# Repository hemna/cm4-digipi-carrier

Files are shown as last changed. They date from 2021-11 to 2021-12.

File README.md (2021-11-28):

# Raspberry Pi Compute Module 4 (CM4) Carrier Template

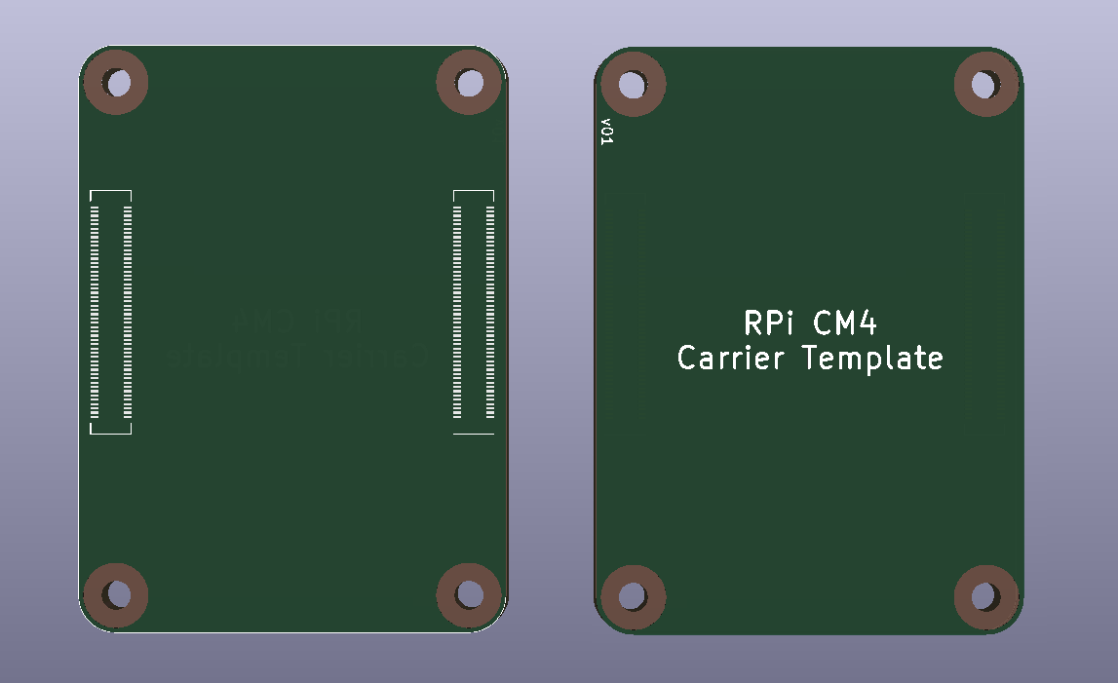
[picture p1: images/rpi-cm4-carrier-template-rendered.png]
Rendered example of RPi CM4 Carrier Template PCB


A template to help you design your own Raspbeery Pi Compute Module 4 carrier board (or daughterboard). The template comes with the CM4 KiCad library and gives an initial placement of Hirose connectors.

Note that a board outline has been added to be the exact size and shape of the CM4 board. This allows you to keep a neat stackup on your carrier board. However, feel free to mvoe/delete the board outline if you wish to make the carrier board extend beyond the edges of the CM4 (e.g. you wish to add a PCIe connector).

**IMPORTANT!** This project require KiCad 6. As KiCad 6 is not out yet, you will need to install a [nightly build of KiCad](https://kicad-downloads.s3.cern.ch/index.html?prefix=windows/nightly/). As a result, you may find bugs in the pre-release of v6.0. Things seem to be working with the 2020-10-29 build for me.

This project uses the CM4 library parts from the IO board KiCad files ([found here](http://datasheets.raspberrypi.org/cm4io/CM4IO-KiCAD.zip)).

## License

Schematic and PCB layout files are licensed under the [CC BY 4.0](https://creativecommons.org/licenses/by/4.0/) license.

Individual components and footprints found in the CM4IO library are licensed as per the Design Files license found [here](https://datasheets.raspberrypi.org/license.html).

THE DESIGN IS PROVIDED "AS IS" AND THE AUTHOR DISCLAIMS ALL WARRANTIES WITH REGARD TO THIS DESIGN INCLUDING ALL IMPLIED WARRANTIES OF MERCHANTABILITY AND FITNESS. IN NO EVENT SHALL THE AUTHOR BE LIABLE FOR ANY SPECIAL, DIRECT, INDIRECT, OR CONSEQUENTIAL DAMAGES OR ANY DAMAGES WHATSOEVER RESULTING FROM LOSS OF USE, DATA OR PROFITS, WHETHER IN AN ACTION OF CONTRACT, NEGLIGENCE OR OTHER TORTIOUS ACTION, ARISING OUT OF OR IN CONNECTION WITH THE USE OR PERFORMANCE OF THIS DESIGN.

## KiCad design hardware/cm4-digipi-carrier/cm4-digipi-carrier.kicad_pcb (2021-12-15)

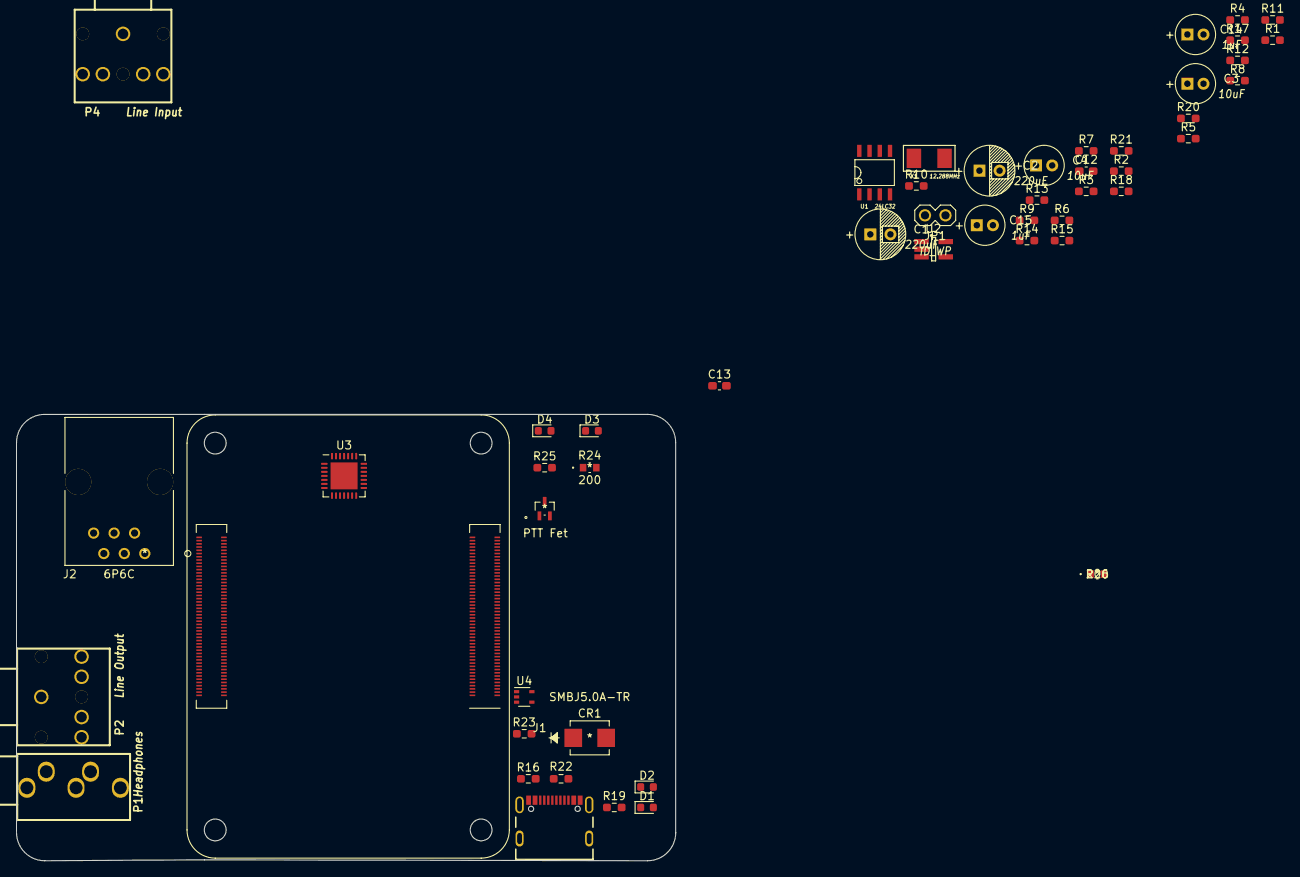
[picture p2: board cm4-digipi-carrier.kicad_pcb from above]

Board: 2 copper layers, 81.8 x 55.4 mm, 52 parts (0 on the bottom side), 52 nets, no tracks yet.

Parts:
C1, C2: 220uF; Cap_Elec_Radial_6.3mm
C3, C4: 10uF; Cap_Elec_Radial_5mm
C12, C13: 22pF; C_0603_1608Metric_Pad1.08x0.95mm_HandSolder
C14, C15: 1uF; Cap_Elec_Radial_5mm
CR1: SMBJ5.0A-TR
D1: LED Green; LED_0603_1608Metric
D2: LED Red; LED_0603_1608Metric
D3: RX LED; LED_0603_1608Metric
D4: PTT LED; LED_0603_1608Metric
J1: USB4105-GF-A; GCT_USB4105-GF-A
J2: 6P6C; SS-90000-003
JP1: ID_WP; Conn_Pin_Header_2x1_2.54mm_NoKey
MOSFET1: PTT Fet; RHU002N06FRAT106
Module1: ComputeModule4-CM4; Raspberry-Pi-4-Compute-Module
P1: Headphones; Conn_Audio_3.5mm_Stereo_SJ1-353XNG
P2: Line Output; Conn_Audio_3.5mm_Stereo
P4: Line Input; Conn_Audio_3.5mm_Stereo
R1, R2: 100; R_0603_1608Metric_Pad0.98x0.95mm_HandSolder
R3, R4, R5, R6: 47k; R_0603_1608Metric_Pad0.98x0.95mm_HandSolder
R7, R8, R9, R10, R14, R15: 33; R_0603_1608Metric_Pad0.98x0.95mm_HandSolder
R11, R19, R23: 1k; R_0603_1608Metric_Pad0.98x0.95mm_HandSolder
R12, R13: 3.9k; R_0603_1608Metric_Pad0.98x0.95mm_HandSolder
R16, R22: 5.1k; R_0603_1608Metric_Pad0.98x0.95mm_HandSolder
R17, R18, R20, R21: 5.6k; R_0603_1608Metric_Pad0.98x0.95mm_HandSolder
R24, R26: 200; ERJ3EKF2000V
R25: 100k; R_0603_1608Metric_Pad0.98x0.95mm_HandSolder
U1: 24LC32; IC_SOIC8_Narrow
U2: TPS79333DBVR; IC_SOT23-5_Hand_Soldering
U3: WM8731CLSEFL; QFN-28-1EP_5x5mm_P0.5mm_EP3.35x3.35mm
U4: 74LVC1G07SE-7; SOT-353_SC-70-5
X1: 12.288MHz; Crystal_5.0x3.2mm

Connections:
+1.8V: Module1.88 (+1.8v_(Output)), Module1.90 (+1.8v_(Output))
+3.3V: D1.2 (A), D2.2 (A), Module1.84 (+3.3v_(Output)), Module1.86 (+3.3v_(Output)), R11.2, R12.2, R13.2, U1.8 (VCC), U3.3 (DCVDD), U3.5 (DBVDD), U4.5 (VCC)
+5V: CR1.1, Module1.77 (+5v_(Input)), Module1.79 (+5v_(Input)), Module1.81 (+5v_(Input)), Module1.83 (+5v_(Input)), Module1.85 (+5v_(Input)), Module1.87 (+5v_(Input)), U2.1 (IN), U2.3 (EN)
/CM4 GPIO/nLED_Activity: Module1.21 (PI_nLED_Activity), R19.2
/CM4 GPIO/nPWR_LED: Module1.95 (nPI_LED_PWR), U4.2
AVDD: U2.5 (OUT), U3.12 (HPVDD), U3.18 (AVDD)
Audio from Radio: J2.6, P4.5, R20.2
Audio to Radio: J2.5, P2.5, R1.1
GND: C12.2, C13.2, CR1.2, J2.1, J2.4, JP1.2, MOSFET1.2, Module1.1 (GND), Module1.2 (GND), Module1.7 (GND), Module1.8 (GND), Module1.13 (GND), Module1.14 (GND), Module1.22 (GND), Module1.23 (GND), Module1.32 (GND), Module1.33 (GND), Module1.42 (GND), Module1.43 (GND), Module1.52 (GND), Module1.53 (GND), Module1.59 (GND), Module1.60 (GND), Module1.65 (GND), Module1.66 (GND), Module1.71 (GND), Module1.74 (GND), Module1.98 (GND), Module1.107 (GND), Module1.108 (GND), Module1.113 (GND), Module1.114 (GND), Module1.119 (GND), Module1.120 (GND), Module1.125 (GND), Module1.126 (GND), Module1.131 (GND), Module1.132 (GND), Module1.137 (GND), Module1.138 (GND), Module1.144 (GND), Module1.150 (GND), Module1.155 (GND), Module1.156 (GND), Module1.161 (GND), Module1.162 (GND), Module1.167 (GND), Module1.168 (GND), Module1.173 (GND), Module1.174 (GND), Module1.179 (GND), Module1.180 (GND), Module1.185 (GND), Module1.186 (GND), Module1.191 (GND), Module1.192 (GND), Module1.197 (GND), Module1.198 (GND), R16.2, R22.2, R24.2, R25.1, R26.2, U1.1 (A0), U1.2 (A1), U1.3 (A2), U1.4 (GND), U2.2 (GND), U3.4 (DGND), U4.3 (GND)
GNDA: P1.1, P2.1, P4.1, R3.1, R4.1, R5.1, R6.1, R17.1, R18.1, U3.15 (HPGND), U3.19 (AGND), U3.25 (MODE), U3.26 (~CSB), U3.29 (AGND)
GPIO12: MOSFET1.1, Module1.31 (GPIO12), R25.2
GPIO16: D3.2 (A), Module1.29 (GPIO16)
GPIO18/PCM_CLK: Module1.49 (GPIO18), R7.1
GPIO19/PCM_FS: Module1.26 (GPIO19), R9.1
GPIO20/PCM_DIN: Module1.27 (GPIO20), R10.1
GPIO21/PCM_DOUT: Module1.25 (GPIO21), R8.1
GPIO26: D4.2 (A), Module1.24 (GPIO26)
ID_SC: Module1.35 (ID_SC), R12.1, U1.6 (SCL)
ID_SD: Module1.36 (ID_SD), R13.1, U1.5 (SDA)
unnamed: C1.1, U3.13 (LHPOUT)
unnamed: C1.2, P1.5, R3.2
unnamed: C2.1, U3.14 (RHPOUT)
unnamed: C2.2, P1.2, R4.2
unnamed: C3.1, U3.16 (LOUT)
unnamed: C3.2, R1.2, R5.2
unnamed: C4.1, U3.17 (ROUT)
unnamed: C4.2, R2.2, R6.2
unnamed: C12.1, U3.2 (XTO), X1.2
unnamed: C13.1, U3.1 (XTI/MCLK), X1.1
unnamed: C14.1, U3.24 (LLINEIN)
unnamed: C14.2, R17.2, R20.1
unnamed: C15.1, U3.23 (RLINEIN)
unnamed: C15.2, R18.2, R21.1
unnamed: D1.1 (K), R19.1
unnamed: D2.1 (K), R23.1
unnamed: D3.1 (K), R24.1
unnamed: D4.1 (K), R26.1
unnamed: J1.A5 (CC1), R16.1
unnamed: J1.B5 (CC2), R22.1
unnamed: JP1.1, R11.1, U1.7 (WP)
unnamed: P2.2, R2.1
unnamed: P4.2, R21.2
unnamed: R7.2, U3.7 (BCLK)
unnamed: R8.2, U3.8 (DACDAT)
unnamed: R9.2, U3.9 (DACLRC), U3.11 (ADCLRC)
unnamed: R10.2, U3.10 (ADCDAT)
unnamed: R15.2, U3.27 (SDIN)
unnamed: R23.2, U4.4
unnamed: R14.2, U3.28 (SCLK)
PTT: J2.2, MOSFET1.3
SCL: Module1.80 (SCL0), R14.1
SDA: Module1.82 (SDA0), R15.1

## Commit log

2021-11-28 Copied from rpi-cm4-carrier-template
    [cm4-gpio.kicad_sch, cm4-high-speed.kicad_sch, rpi-cm4-carrier-template.kicad_pcb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]
2021-12-15 Initial Commit.
    [audio.kicad_sch, cm4-digipi-carrier.kicad_pcb, cm4-digipi-carrier.kicad_sch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]

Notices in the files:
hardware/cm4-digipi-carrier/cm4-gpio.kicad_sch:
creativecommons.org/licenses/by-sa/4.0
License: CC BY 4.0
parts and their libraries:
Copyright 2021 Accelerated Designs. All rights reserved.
